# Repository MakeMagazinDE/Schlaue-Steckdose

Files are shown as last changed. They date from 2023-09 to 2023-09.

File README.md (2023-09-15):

GitHub Logo

Maker Media GmbH

***

# Schlaue Steckdose

**Steckdosen, die man über das Handy schalten kann, sind nichts Neues. Auch gibt es Mehrfachsteckdosen, die nur Strom verteilen, wenn ein bestimmtes Gerät an ist. Das alles ist unserem Autor nicht genug und deshalb hat er sich eine Steckdosenleiste gebaut, die Geräte abhängig von seiner Anwesenheit mit Strom versorgt oder bei bestimmten Temperaturen die Heizung regelt.**

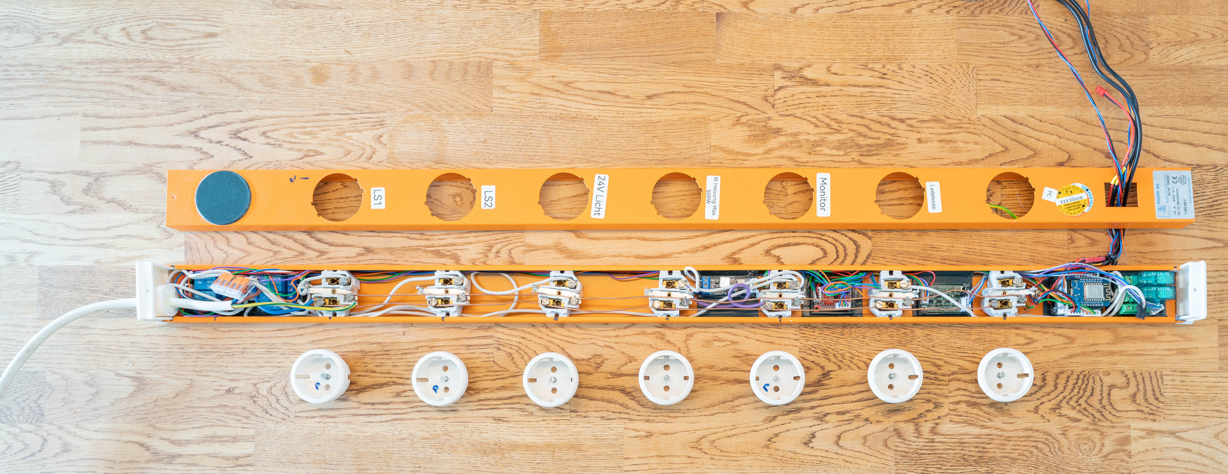
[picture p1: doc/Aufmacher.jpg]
Aufmacherbild aus dem Heft


Der vollständige Artikel zum Projekt steht in der **[Make-Ausgabe 5/23 ab Seite 54](https://www.heise.de/select/make/2023/5)**.

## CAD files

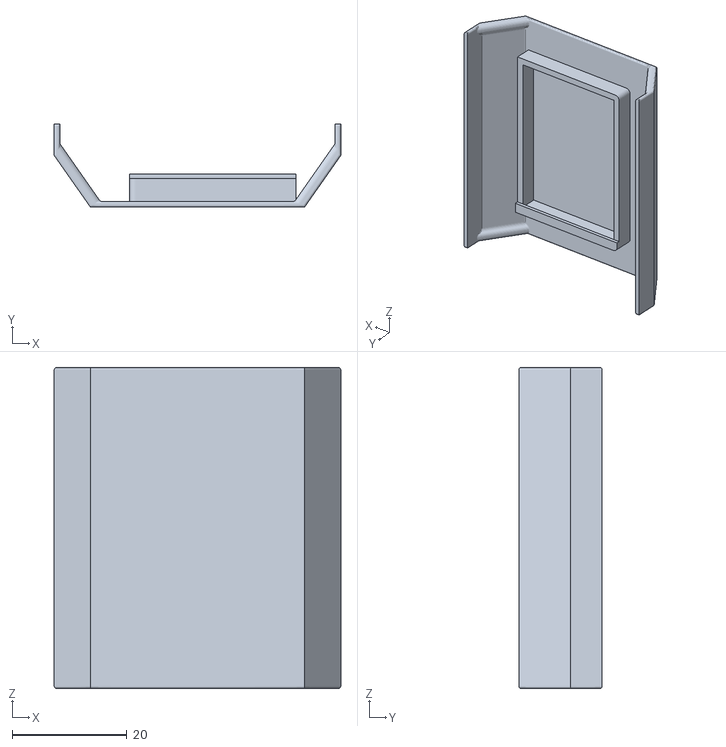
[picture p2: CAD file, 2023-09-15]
3D-Druck/schiffchen halter IO expand.stl
50.0 x 14.5 x 56.0

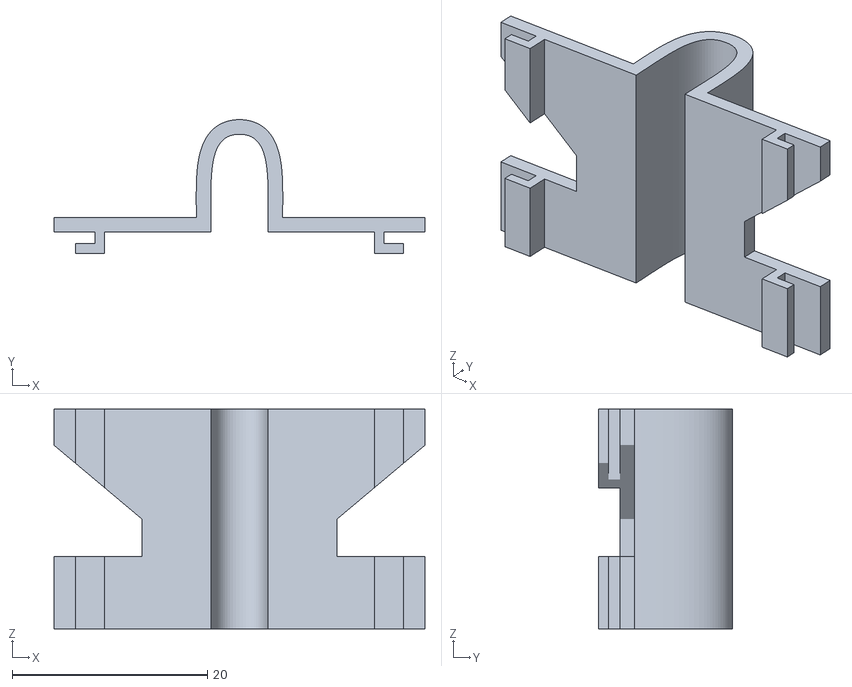
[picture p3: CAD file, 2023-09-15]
3D-Druck/kabeldeckel.stl
38.0 x 13.7 x 22.5

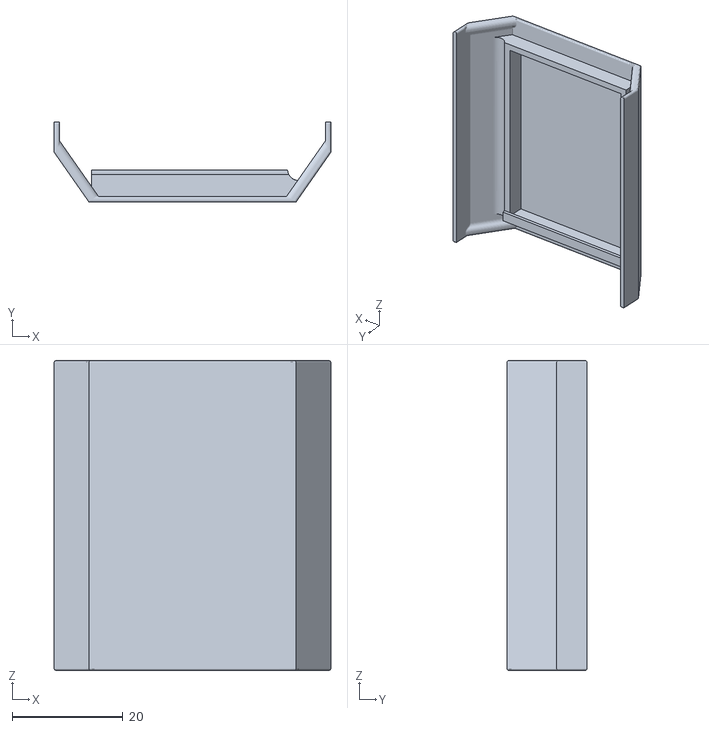
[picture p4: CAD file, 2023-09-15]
3D-Druck/office Schaltleiste rel.stl
50.0 x 14.5 x 56.0

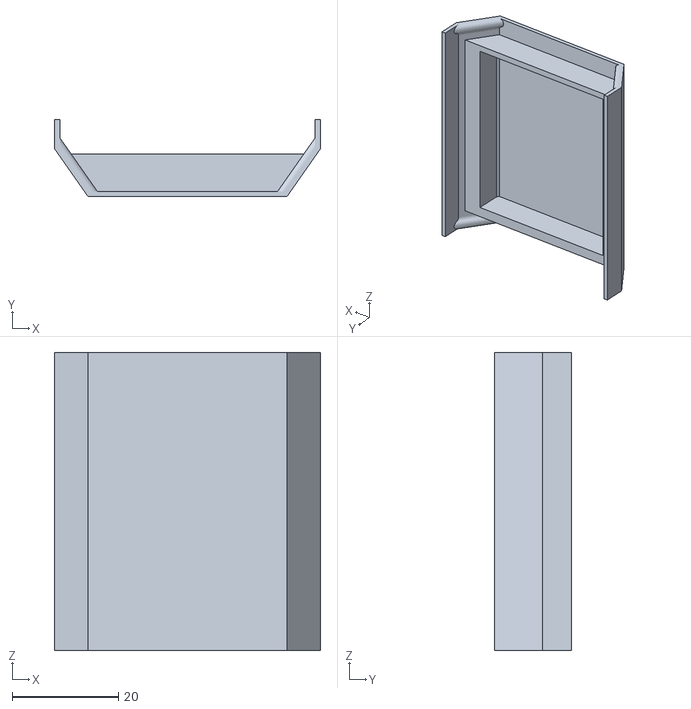
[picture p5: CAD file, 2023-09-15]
3D-Druck/office Schaltleiste bS rel.stl
50.0 x 14.5 x 56.0

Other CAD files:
3D-Druck/office Schaltleiste wemos.stl

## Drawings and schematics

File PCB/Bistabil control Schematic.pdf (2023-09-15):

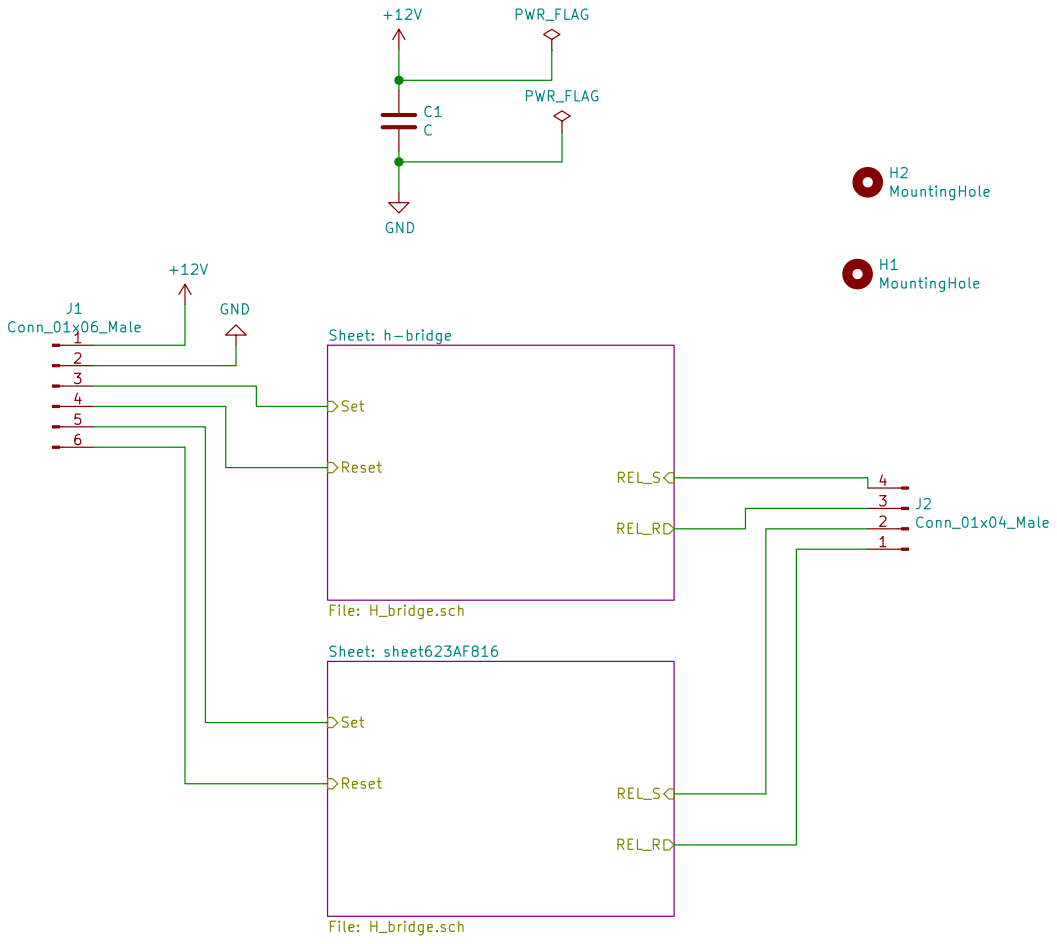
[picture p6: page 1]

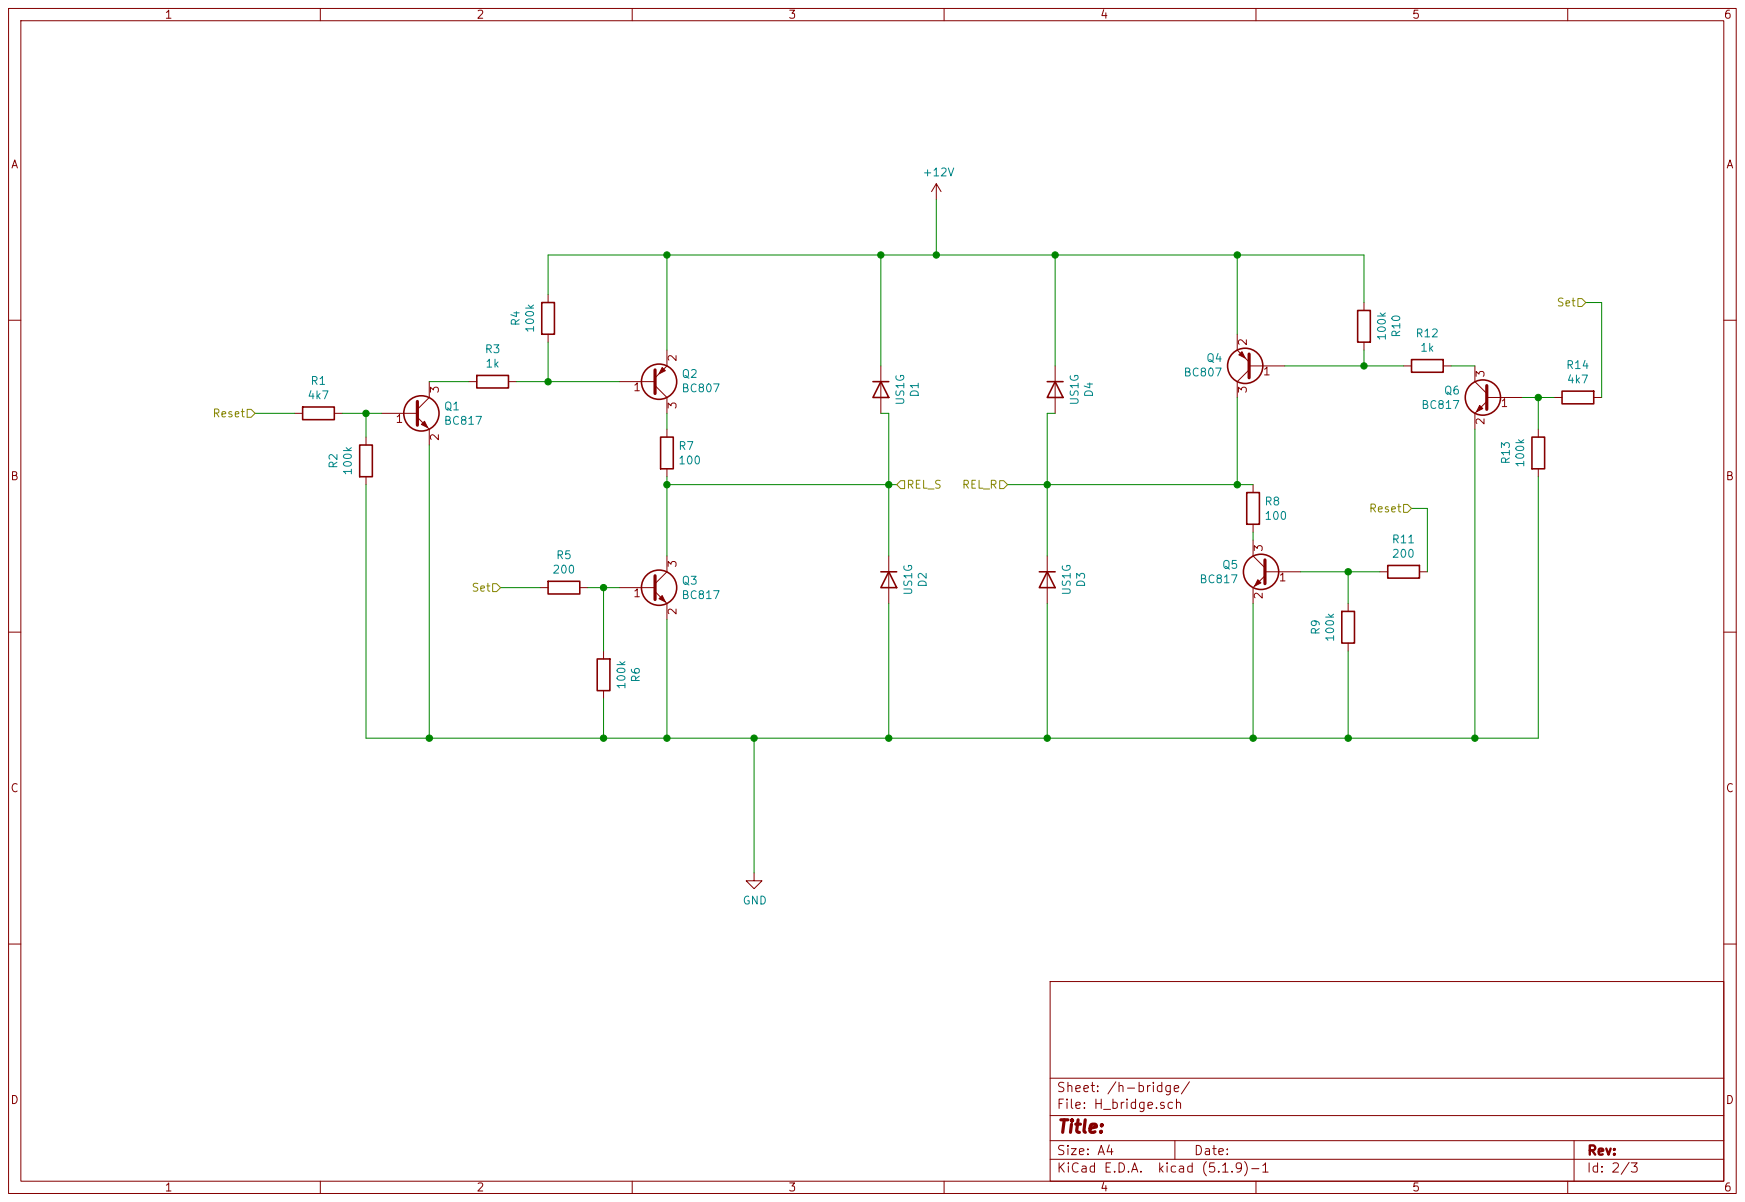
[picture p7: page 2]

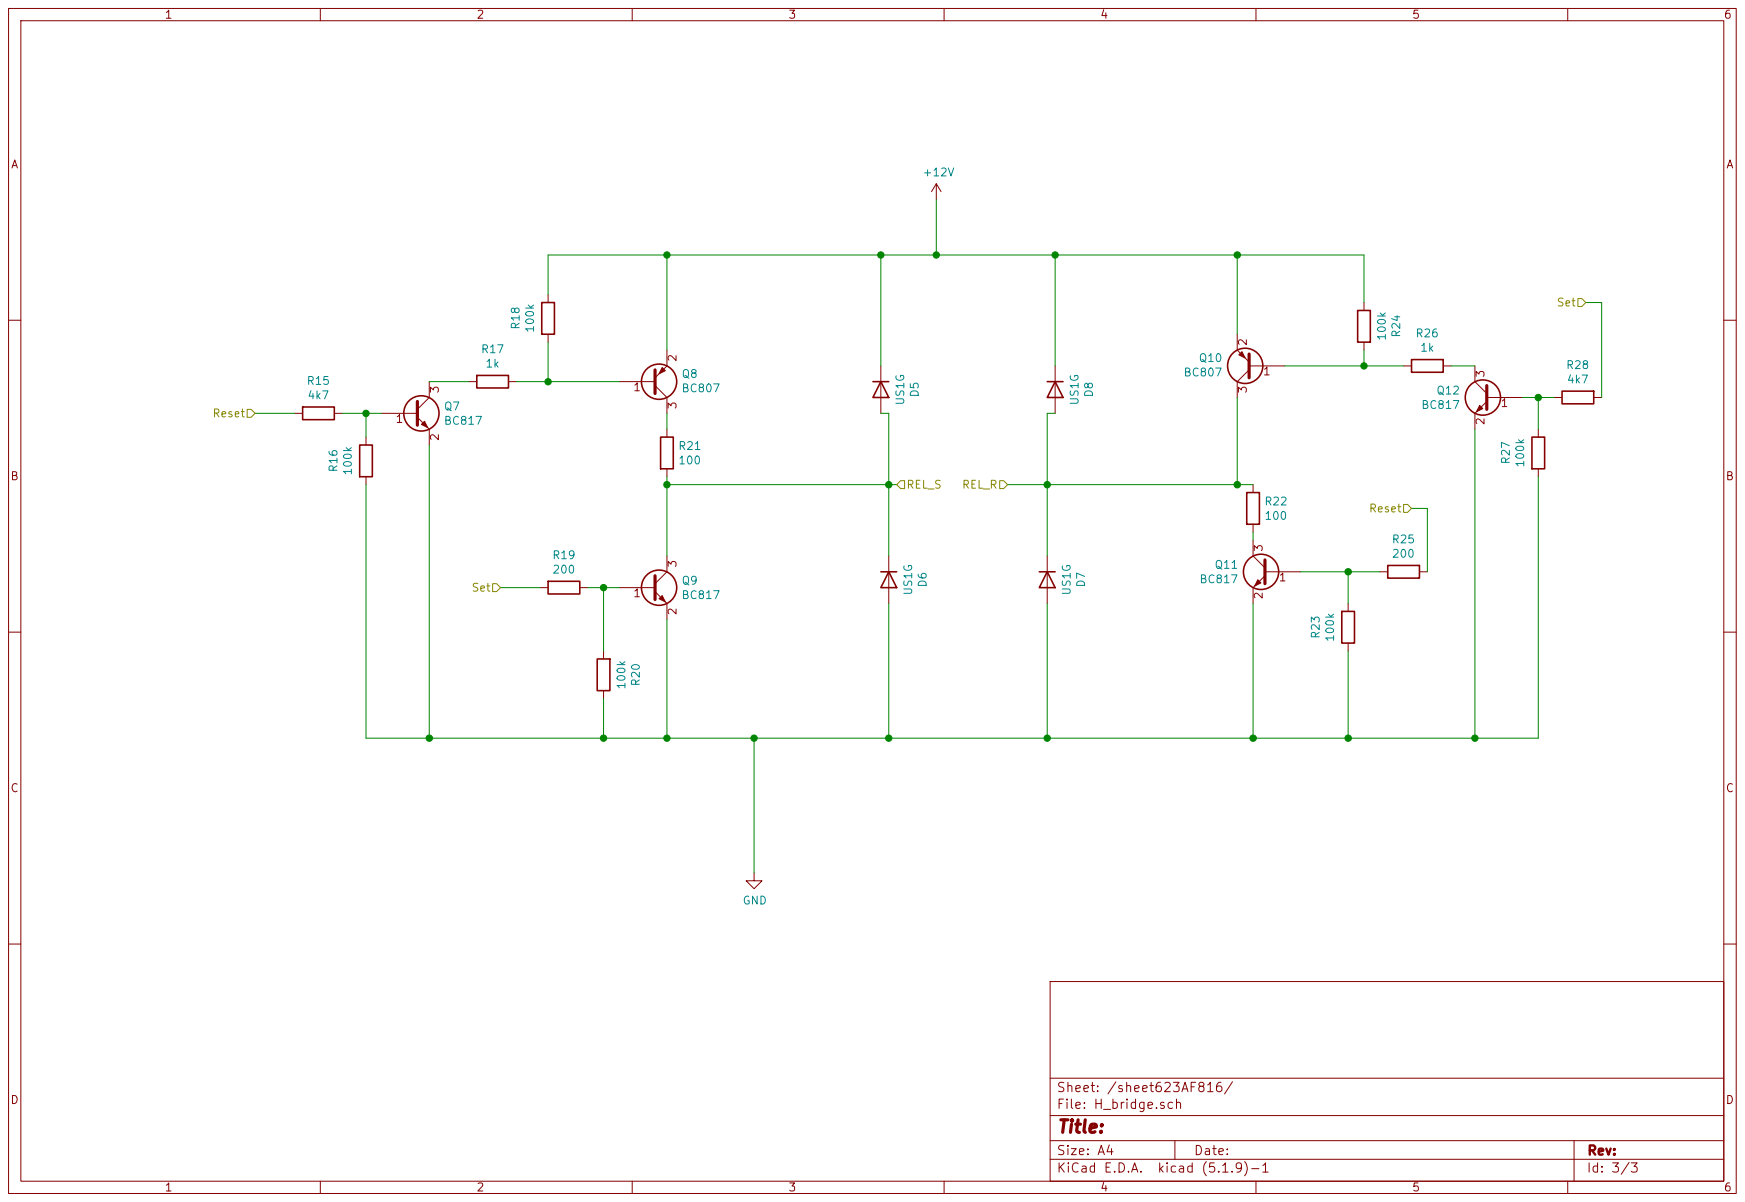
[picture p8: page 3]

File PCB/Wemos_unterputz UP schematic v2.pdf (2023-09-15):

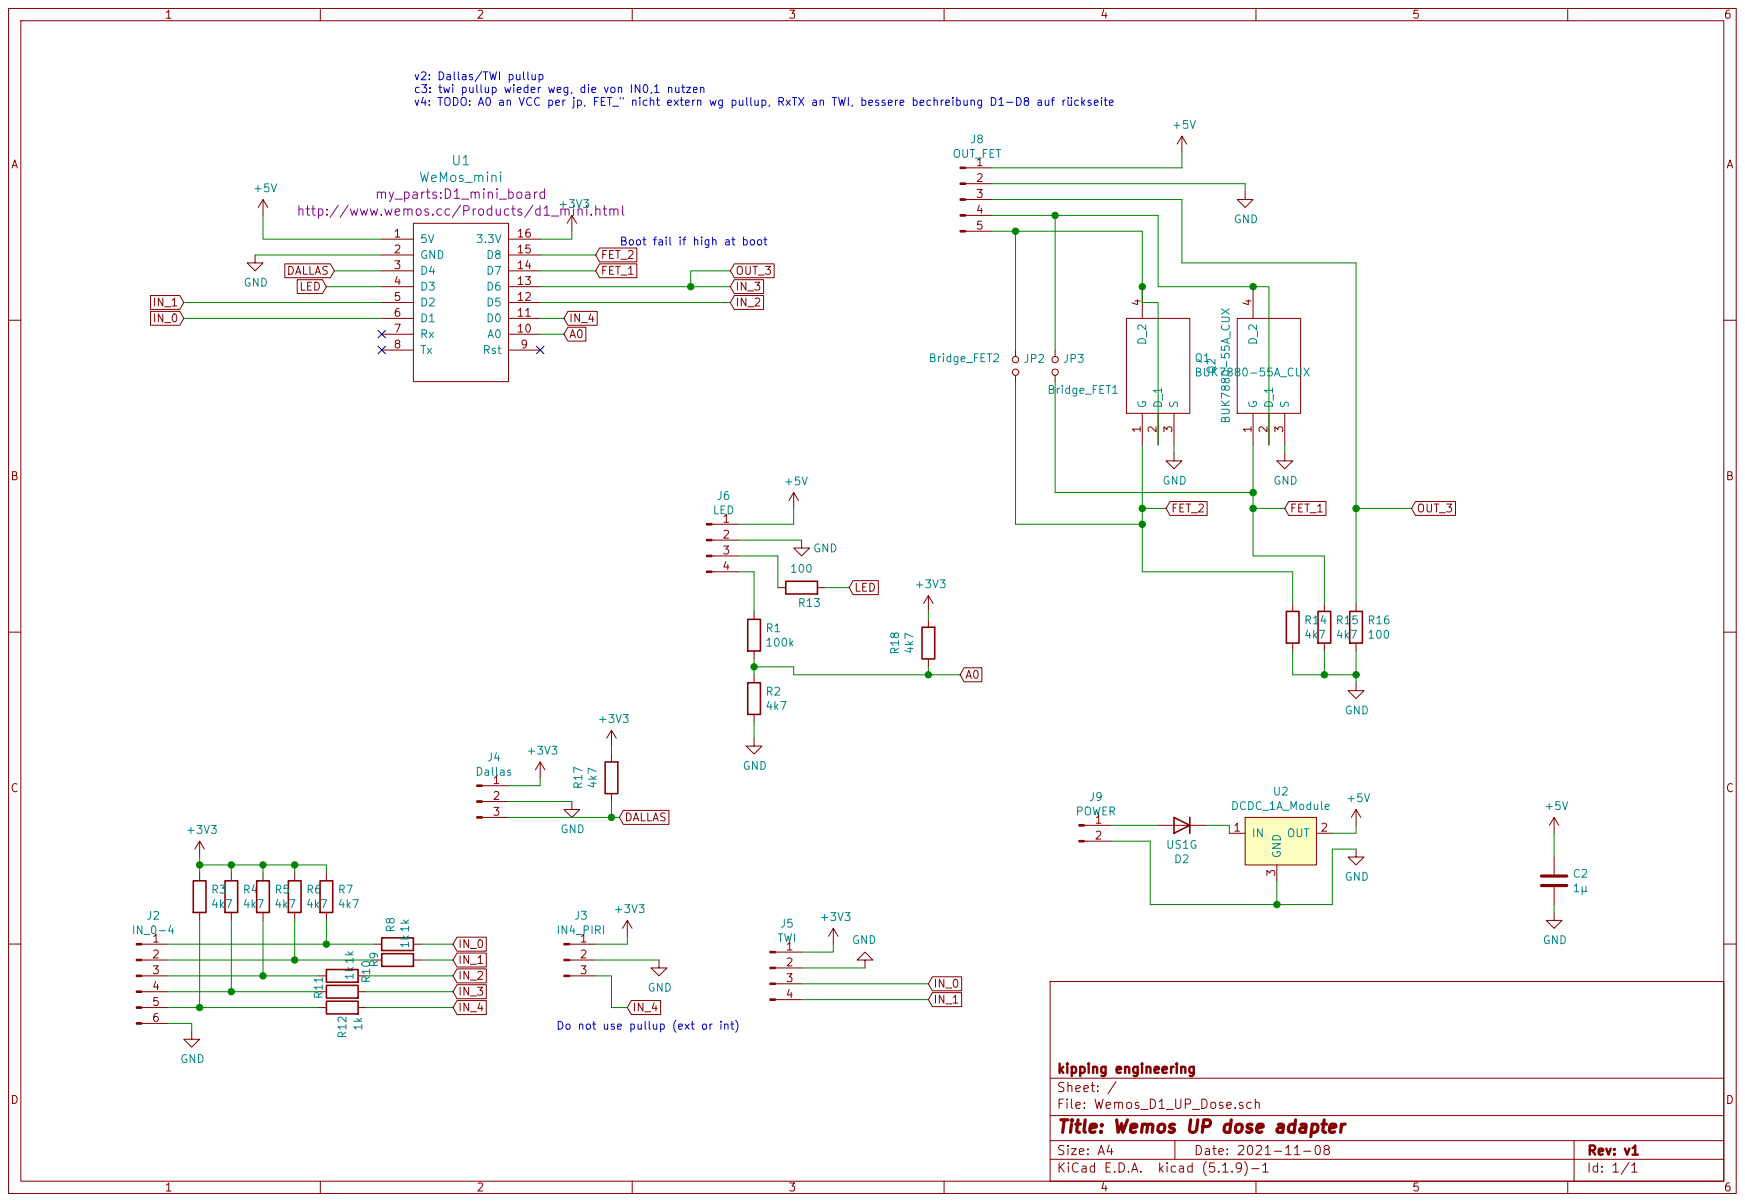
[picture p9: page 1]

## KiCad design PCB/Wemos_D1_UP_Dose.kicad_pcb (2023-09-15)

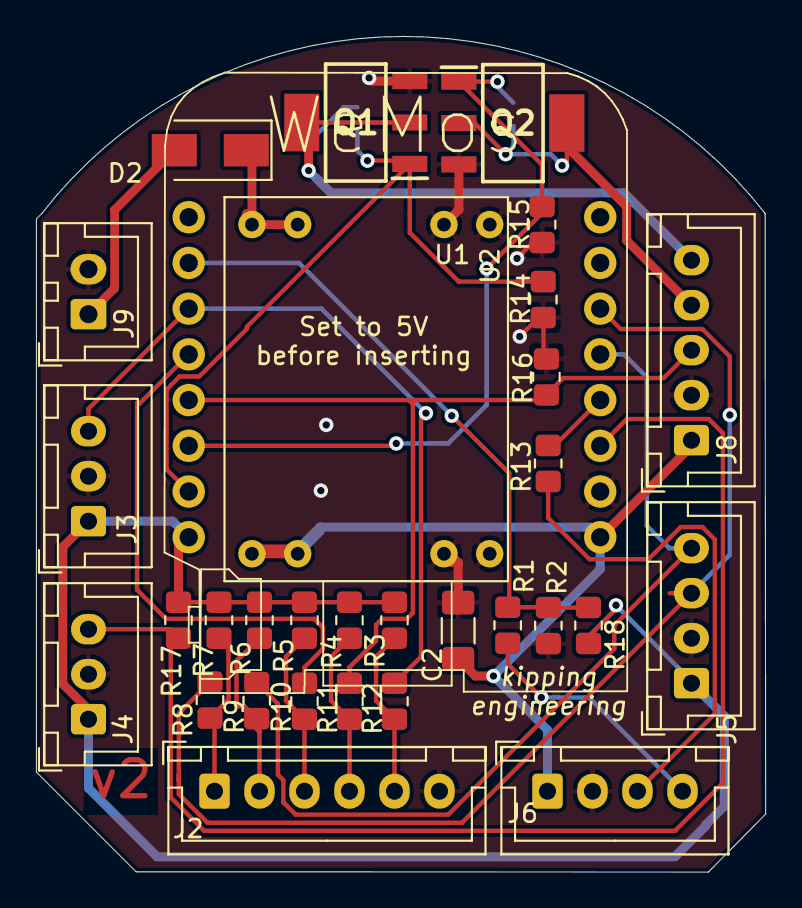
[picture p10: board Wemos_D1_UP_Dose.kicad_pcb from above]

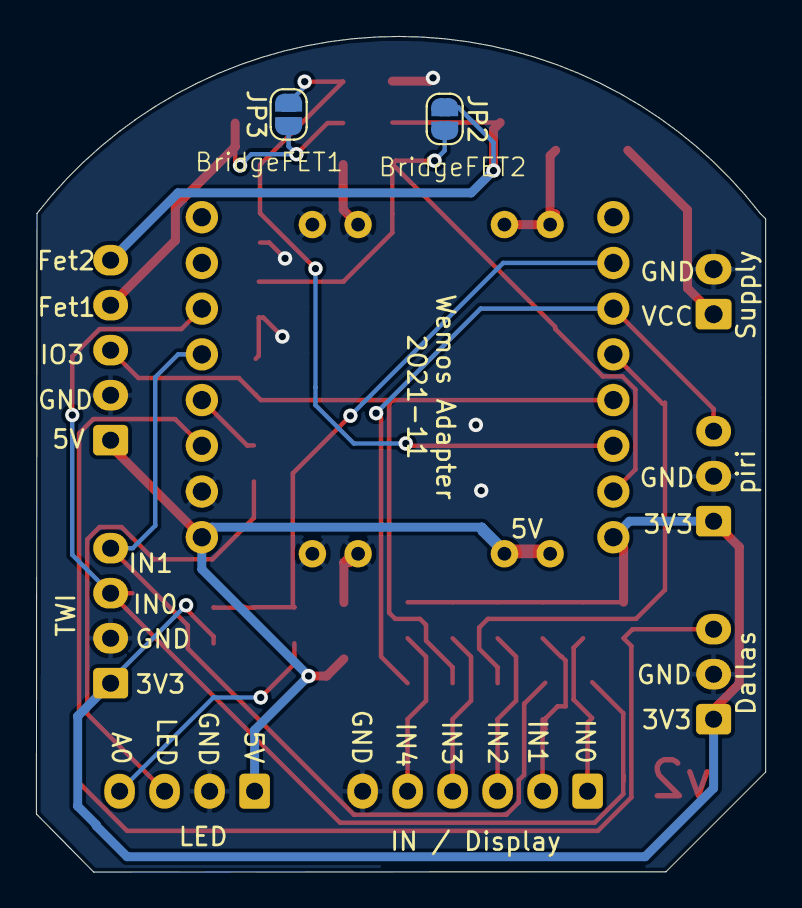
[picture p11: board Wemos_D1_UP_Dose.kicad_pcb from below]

Board: 2 copper layers, 40.5 x 46.4 mm, 33 parts (2 on the bottom side), 24 nets.

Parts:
C2: 1µ; C_1206_3216Metric_Pad1.33x1.80mm_HandSolder
D2: US1G; D_SMA
J2: IN_0-4; JST_XH_B6B-XH-A_1x06_P2.50mm_Vertical
J3: IN4_PIRI; JST_XH_B3B-XH-A_1x03_P2.50mm_Vertical
J4: Dallas; JST_XH_B3B-XH-A_1x03_P2.50mm_Vertical
J5: TWI; JST_XH_B4B-XH-A_1x04_P2.50mm_Vertical
J6: LED; JST_XH_B4B-XH-A_1x04_P2.50mm_Vertical
J8: OUT_FET; JST_XH_B5B-XH-A_1x05_P2.50mm_Vertical
J9: POWER; JST_XH_B2B-XH-A_1x02_P2.50mm_Vertical
JP2, JP3: Jumper_NO_Small; SolderJumper-2_P1.3mm_Open_RoundedPad1.0x1.5mm
Q1, Q2: BUK7880-55A_CUX; SOT230P700X180-4N
R1: 100k; R_0805_2012Metric_Pad1.20x1.40mm_HandSolder
R2, R3, R4, R5, R6, R7, R14, R15, R17, R18: 4k7; R_0805_2012Metric_Pad1.20x1.40mm_HandSolder
R8, R9, R10, R11, R12: 1k; R_0805_2012Metric_Pad1.20x1.40mm_HandSolder
R13, R16: 100; R_0805_2012Metric_Pad1.20x1.40mm_HandSolder
U1: WeMos_mini; D1_mini_board
U2: DCDC_1A_Module; DCDC_1A_module

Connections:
+3V3: J3.1, J4.1, J5.1, R3.1, R4.1, R5.1, R6.1, R7.1, R17.2, R18.2, U1.16
+5V: C2.1, J6.1, J8.1, U1.1, U2.2
A0: R1.2, R2.1, R18.1, U1.10
DALLAS: J4.3, R17.1, U1.3
FET_1: JP3.2, Q2.1, R15.1, U1.14
FET_2: JP2.2, Q1.1, R14.1, U1.15
GND: C2.2, J2.6, J3.2, J4.2, J5.2, J6.2, J8.2, J9.2, Q1.3, Q2.3, R2.2, R14.2, R15.2, R16.2, U1.2, U2.3
IN_0: J5.3, R8.2, U1.6
IN_1: J5.4, R9.2, U1.5
IN_2: R10.2, U1.12
IN_3: J8.3, R11.2, R16.1, U1.13
IN_4: J3.3, R12.2, U1.11
LED: R13.2, U1.4
unnamed: D2.1, U2.1
unnamed: D2.2, J9.1
unnamed: J2.1, R7.2, R8.1
unnamed: J2.2, R6.2, R9.1
unnamed: J2.3, R5.2, R10.1
unnamed: J2.4, R4.2, R11.1
unnamed: J2.5, R3.2, R12.1
unnamed: J6.3, R13.1
unnamed: J6.4, R1.1
unnamed: J8.4, JP3.1, Q2.2, Q2.4
unnamed: J8.5, JP2.1, Q1.2, Q1.4

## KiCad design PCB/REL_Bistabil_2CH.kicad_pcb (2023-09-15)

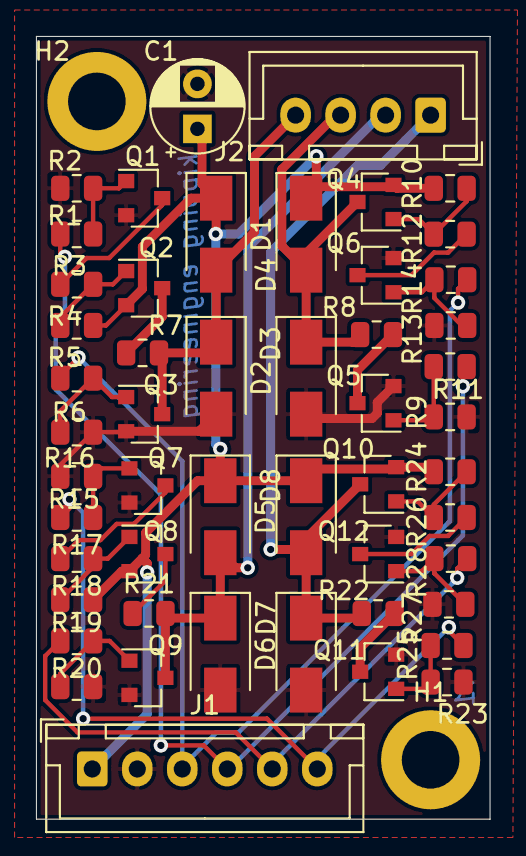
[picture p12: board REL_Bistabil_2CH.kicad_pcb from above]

Board: 2 copper layers, 25.2 x 43.5 mm, 53 parts (0 on the bottom side), 30 nets.

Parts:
C1: C; CP_Radial_D5.0mm_P2.50mm
D1, D2, D3, D4, D5, D6, D7, D8: US1G; D_SMA
H1, H2: MountingHole; MountingHole_3.2mm_M3_ISO14580_Pad
J1: Conn_01x06_Male; JST_XH_B6B-XH-A_1x06_P2.50mm_Vertical
J2: Conn_01x04_Male; JST_XH_B4B-XH-A_1x04_P2.50mm_Vertical
Q1, Q3, Q5, Q6, Q7, Q9, Q11, Q12: BC817; SOT-23
Q2, Q4, Q8, Q10: BC807; SOT-23
R1, R14, R15, R28: 4k7; R_0805_2012Metric
R2, R4, R6, R9, R10, R13, R16, R18, R20, R23, R24, R27: 100k; R_0805_2012Metric
R3, R12, R17, R26: 1k; R_0805_2012Metric
R5, R11, R19, R25: 200; R_0805_2012Metric
R7, R8, R21, R22: 100; R_0805_2012Metric

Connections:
+12V: C1.1, D1.1, D4.1, D5.1, D8.1, J1.1, Q2.2, Q4.2, Q8.2, Q10.2, R4.1, R10.1, R18.1, R24.1
/h-bridge/REL_R: D3.1, D4.2, J2.3, Q4.3, R8.1
/h-bridge/REL_S: D1.2, D2.1, J2.4, Q3.3, R7.2
/h-bridge/Reset: J1.4, R1.2, R11.2
/h-bridge/Set: J1.3, R5.2, R14.2
/sheet623AF816/REL_R: D7.1, D8.2, J2.1, Q10.3, R22.1
/sheet623AF816/REL_S: D5.2, D6.1, J2.2, Q9.3, R21.2
/sheet623AF816/Reset: J1.6, R15.2, R25.2
/sheet623AF816/Set: J1.5, R19.2, R28.2
GND: C1.2, D2.2, D3.2, D6.2, D7.2, J1.2, Q1.2, Q3.2, Q5.2, Q6.2, Q7.2, Q9.2, Q11.2, Q12.2, R2.2, R6.1, R9.1, R13.2, R16.2, R20.1, R23.1, R27.2
unnamed: Q1.1, R1.1, R2.1
unnamed: Q1.3, R3.2
unnamed: Q2.1, R3.1, R4.2
unnamed: Q2.3, R7.1
unnamed: Q3.1, R5.1, R6.2
unnamed: Q4.1, R10.2, R12.1
unnamed: Q5.1, R9.2, R11.1
unnamed: Q5.3, R8.2
unnamed: Q6.1, R13.1, R14.1
unnamed: Q6.3, R12.2
unnamed: Q7.1, R15.1, R16.1
unnamed: Q7.3, R17.2
unnamed: Q8.1, R17.1, R18.2
unnamed: Q8.3, R21.1
unnamed: Q9.1, R19.1, R20.2
unnamed: Q10.1, R24.2, R26.1
unnamed: Q11.1, R23.2, R25.1
unnamed: Q11.3, R22.2
unnamed: Q12.1, R27.1, R28.1
unnamed: Q12.3, R26.2

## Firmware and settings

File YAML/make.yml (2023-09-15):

substitutions:
  plug_name: "office_jan"
  ip_adress: "192.168.178.112"
  presence_debounce_time: 30min
  irheat_max_power: "260"
  pc_on_power: "250"
  speaker_on_power: "20"
  display_on_power: "80"

esphome:
  name: "office_jan"
  on_boot: 
    then:
      - delay: 400ms
      - switch.turn_on: bs_rel_pc_supply



esp8266:
  board: d1_mini

# Enable logging
logger:


debug:
  update_interval: 5s


packages:
  device_base: !include device_base.yaml      



i2c:
  sda: D2
  scl: D1
  scan: true
  id: i2c_a  

sx1509:
  - id: sx1509_hub1
    address: 0x3E

dallas:
  - pin: D4
    update_interval: 20sec

# ---------------------- user ----------------------------

number:
  - platform: template
    name: "Office IR Heizung Obere Grenze"
    id: heater_max_temp
    unit_of_measurement: "°C"
    optimistic: true
    restore_value: true
    min_value: 10
    max_value: 30
    step: 1


  - platform: template
    name: "Office IR Heizung Untere Grenze"
    id: heater_min_temp
    unit_of_measurement: "°C"
    optimistic: true
    restore_value: true
    min_value: 10
    max_value: 30
    step: 1



  - platform: template
    name: "Office Heizung IR Ansteuerung"
    id: ir_heat_relative_request
    optimistic: true
    entity_category: "diagnostic"
    unit_of_measurement: "%"
    min_value: 0
    max_value: 100
    step: 1     


globals:
   - id: my_ac_dimmer_power
     type: float
     restore_value: no
     initial_value: '0'


# ------------------   Eingänge   --------------------------------

binary_sensor:
  - platform: gpio
    id: gpio_presence
    name: "Office Anwesenheit"
    device_class: presence  
    pin: 
      number: D0
      mode: INPUT
    filters:
      - delayed_off: ${presence_debounce_time}
    on_press:
      then:
        - lambda: if(id(pc_an).state) {id(office_speaker).turn_on();}
    on_release:
      then:
        - switch.turn_off : office_speaker


  - platform: gpio
    id: pc_an
    name: "Office PC"
    pin: 
      number: D5
      mode: INPUT
      inverted: true
    device_class: power
    filters:
      - delayed_off: 5000ms
    on_press:
      then:
        - logger.log: 
            format: "PC an!"
            level: INFO
        - switch.turn_on : sw_display
    on_release:
      then: 
        - switch.turn_off : office_speaker
        - switch.turn_off : sw_display
        - delay: 50ms
        - switch.turn_on : sw_display
        - delay: 50ms
        - switch.turn_off : sw_display
        - delay: 50ms
        - switch.turn_on : sw_display
        - delay: 50ms
        - switch.turn_off : sw_display


sensor:
  - platform: template
    name: "Office Heizung Ansteuerung"
    id: heater_value
    icon: "mdi:valve"
    lambda: |-
      if (isnan(id(ir_surface_temp).state) || 
        ((id(heater_max_temp).state - id(heater_min_temp).state) == 0))
      {
        ESP_LOGI("main", "Invalid input %f", id(ir_surface_temp).state);
        return id(heater_value).state;

      } else {
        float new_val;
        new_val = (id(heater_max_temp).state - id( office_desk_temp).state ) * 100 /
                  (id(heater_max_temp).state  - id(heater_min_temp).state );
        if (new_val > 100) new_val = 100;
        // nur heizen, wenn PC an und jemand da:
        if (new_val < 0 || !id(pc_an).state || !id(gpio_presence).state )  new_val = 0;
        id(dimmer1).set_level(new_val / 100);
        return new_val;

      }
    unit_of_measurement: "%"
    update_interval: 6s



  - platform: template
    name: "Office AC Leistung"
    id: power_ac_sum
    icon: "mdi:power"
    lambda: |-
      float power_sum = 0;
      if (id(sw_display).state) {
        power_sum += ${display_on_power};  
      }
      if (id(pc_an).state) {
        power_sum += ${pc_on_power};  
      }
      if (id(office_speaker).state) {
        power_sum += ${speaker_on_power};  
      }
      power_sum += id(heater_value).state / 100 * ${irheat_max_power} ;  
      return power_sum;
    unit_of_measurement: "W"
    update_interval: 20s



  - platform: dallas
    address: 0xed3c02f649eb1828
    name: "Office Temperatur Umgebung"
    id: office_desk_temp_raw
    filters:    
      - sliding_window_moving_average:
          window_size: 4
          send_every: 2  
      - or:
          - delta: 0.2
          - throttle: 10min
          
  - platform: dallas
    address: 0x203c2af648f5eb28
    name: "Office Temperatur IR Heizung Oberfläche"
    id: ir_surface_temp_raw
    filters:    
      - sliding_window_moving_average:
          window_size: 2
          send_every: 2  
      - or:
          - delta: 0.2
          - throttle: 10min
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
